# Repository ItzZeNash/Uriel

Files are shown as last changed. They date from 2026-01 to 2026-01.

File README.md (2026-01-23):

Fully assembled in fusion 
For assembly solder on the kalih hotswap sockets, the jst connector which is through hold along with the nice!nano clone which is mounted on the backside of the board flipped. The diodes should also be soldered on the backside with the black line on the side of the sqaure hole.Also connect the battery with the jst connector.  After that put on the orings on the protrusions on the pcb then put it into the case(the case should already have 5 layers put together(the solid base the hollow rings x 3, and the gasket holder, after that lay it onto the gasket holder which will support the pcb, then add the other gasket holder to make sure it holds, then add the top 2 whihc inlude a cutout for the usb, then add screws to fasten the case. After that add the m2 standoffs on the pcb where the controller and the silkscreen is then add it onto the holds then screw onto the small acrylic cover and you are finished.

Idk how to do keycaps and nice nano itll be also itll be wayy to complicated for me ._.

# Uriel
A 40% keyboard 
PCB - 


Schem-


Bom

# Bill of Materials (BOM) — Custom 40% Keybiard

| # | Component | Qty | Description / Specs | Part / Model | Price (USD) | Source / Link | Notes |
|---|---|-----|---|---|---|---|---|
| 1 | Wireless Controller | 2 | NRF52840 dev board, Nice!Nano v2 compatible, BLE + charging, Pro Micro footprint | Nice!Nano alternative | **$4.34 each ($8.68)** | https://www.ebay.com/itm/405014063318 | Use as nice_nano_v2 in ZMK. Deep sleep ~1mA. |
| 2 | Keyboard Switches | 90 | Akko Rosewood Linear, 5-pin MX, 40gf, factory lubed | Akko Rosewood | **$29.46 total** | https://www.aliexpress.com/item/1005007227966289.html | 47 used, extras for future builds. |
| 3 | Switching Diodes | 50 | 1N4148 | 1N4148 pack | **$3.00** | https://www.mouser.com/ProductDetail/onsemi/1N4148TR?qs=i4Fj9T%2FoRm%252BOzV8sfXrhvQ%3D%3D | 1 per key + spares. |
| 4 | Reset Tactile Switch | 2 | Right-angle, grounding, 6mm tact, SPST-NO | MJTP1117 | **$0.61 each ($1.22)** | https://www.mouser.com/ProductDetail/642-MJTP1117 | SW2 in schematic. |
| 5 | Controller Socket Pins | ~48 pins | Mill-Max low-profile sockets | 315-43-112-41-003000 | **$5.00** | https://www.mill-max.com | For Pro Micro/Nice!Nano footprint. |
| 6 | Extra IC Socket Pins | 30+ | Mill-Max standard pins | 03320-000-15-000-003-0 | **$2.28** | https://www.mouser.com | For I2C header J1 (OLED/rotary). |
| 7 | LiPo Battery | 1 | 3.7V 2000mAh with JST | EHB 105454A | **$11.99** | — | One battery for wireless half. |
| 8 | Case / Dampening Foam | 1–2 sheets | 3mm PORON/IXPE foam | MEARCOOH 3mm | **$9.96** | — | Sound dampening inside case. |
| 9 | Misc Hardware | Various | Standoffs, screws, bumpers, O-rings | Assorted | **$40.00** | — | Includes PCB standoffs, bumpers, etc. |
| 10 | Hotswap Sockets | 50 | Kailh MX hotswap sockets | Kailh CPG151101 | **$15.00** | https://www.amazon.com/dp/B0BVH6M5FP | Optional. |
| 11 | Keycaps | 1 set | Doubleshot PBT keycaps | Generic | **$13.00** | https://www.amazon.com/gp/product/B0D1JWX3PP | — |

---

## 💵 Total Estimated Cost

**~$253.69 USD** Somewhere there 
Decreased the price with this

Breakdown:
- Controllers: $8.68  
- Switches: $29.46  
- Diodes: $3  
- Reset switches: $1.22  
- Mill‑Max low‑profile: $5  
- Mill‑Max standard: $2.28  
- Battery: $11.99  
- Foam: $9.96  
- Misc hardware: $40  
- Hotswap sockets: $15  
- Keycaps: $13  

**Grand Total: $140.59**









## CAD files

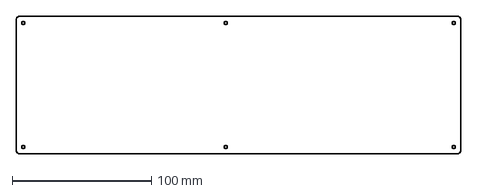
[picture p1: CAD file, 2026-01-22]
CAD/Complete bottom for uriel.dxf
319.6 x 99.2 mm

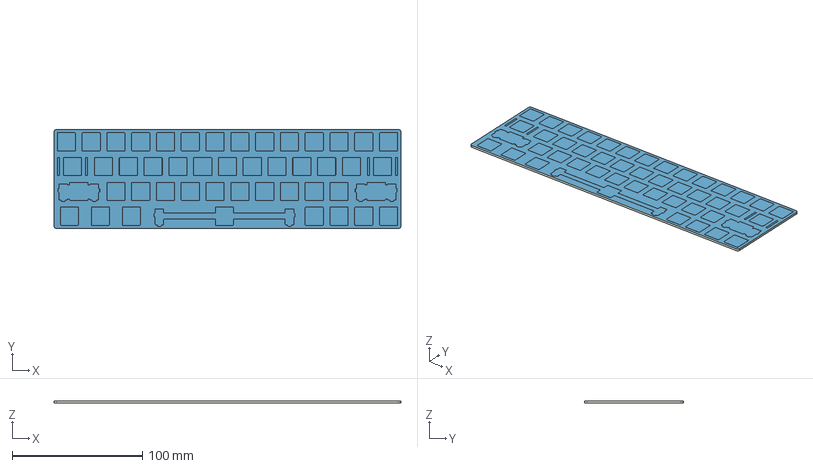
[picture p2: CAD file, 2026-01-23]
GERBERS/3D_PCB1_2026-01-22.step
266.7 x 76.2 x 1.60 mm
Board~3INC
TopCopper~3INC
BottomCopper~3INC
TopFpcStiffener~3INC
BottomFpcStiffener~3INC

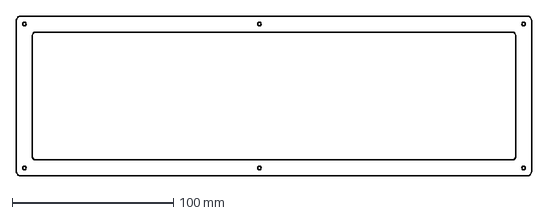
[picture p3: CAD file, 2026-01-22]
CAD/Uriel bottom 2.dxf
319.6 x 99.2 mm

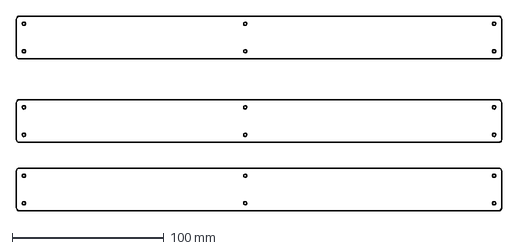
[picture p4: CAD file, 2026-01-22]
CAD/Uriel incliners set of 3.dxf
319.6 x 128.1 mm

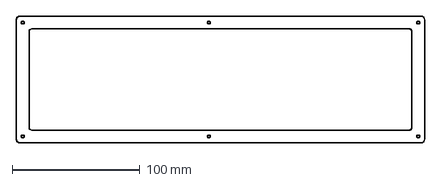
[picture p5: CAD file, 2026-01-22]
CAD/Uriel Base.dxf
319.6 x 99.2 mm

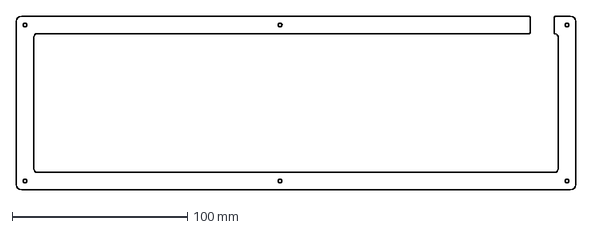
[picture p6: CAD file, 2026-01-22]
CAD/Uriel top pt1.dxf
319.6 x 99.2 mm

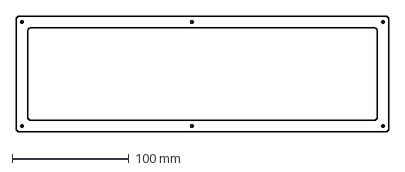
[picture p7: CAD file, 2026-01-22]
CAD/Uriel bottom 3.dxf
319.6 x 99.2 mm

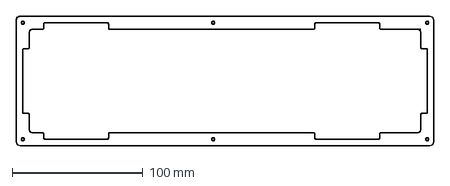
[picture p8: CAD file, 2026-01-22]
CAD/Uriel gasket 2 out of 2.dxf
319.6 x 99.2 mm

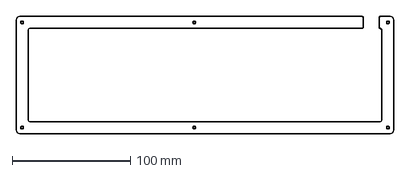
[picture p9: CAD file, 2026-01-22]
CAD/Uriel top pt2.dxf
319.6 x 99.2 mm

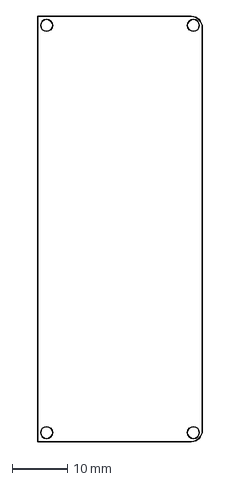
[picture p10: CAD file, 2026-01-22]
CAD/Uriel Display and processor cover.dxf
29.9 x 77.2 mm

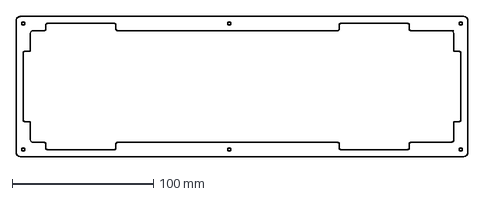
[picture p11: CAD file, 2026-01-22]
CAD/Uriel gasket 1 out of 2.dxf
319.6 x 99.2 mm

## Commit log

2025-12-31 Add new temporary file in Gerbers directory
2025-12-31 Add new temporary file in PCB directory
2025-12-31 Enhance README with PCB and schematic images
    Added images for PCB and schematic to README.
2026-01-01 Add new temporary file in CAD directory
2026-01-22 Update hotswap sockets quantity and link
    Updated the quantity of hotswap sockets and modified the AliExpress link for better clarity.
2026-01-22 Revise BOM for Custom 47-Key Split Ergo Keyboard
    Updated the Bill of Materials (BOM) for the custom keyboard, including component details, quantities, prices, and sources.
2026-01-22 Update BOM title and correct keyboard type
2026-01-22 Add files via upload
    Acrylic case files
    [Complete bottom for uriel.dxf, Uriel Base.dxf, Uriel Display and processor cover.dxf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]
2026-01-23 Add files via upload
    Upladed the step of the pcb and plate
    [3D_PCB1_2026-01-22.step]
2026-01-23 Add files via upload
    Plate gerbers
2026-01-23 Enhance README with assembly instructions
    Added detailed assembly instructions for the keyboard.
2026-01-23 Add files via upload
    plate
    [3D_PCB1_2026-01-22.step]
